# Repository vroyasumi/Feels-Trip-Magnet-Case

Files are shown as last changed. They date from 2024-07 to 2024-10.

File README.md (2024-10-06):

# Feels Trip Magnet Case (v1.1)

Intended for use with the Feels Trip PCB.¹

This case was designed with the intent of being manufactured via 3D Printers. Manufacturing via Resin and CNC has not been tested.

<sub>¹ Feels Trip PCB designed by CyberJedi.</sub>

## Updates (as of July 18, 2024)

v1 - Utilizes 12 magnets total.

v1.1 - Utilizes 20 magnets total; Updated magnet slots.

v1.2 TBA - Updated magnet slots to prevent magnet slippage; Added weight design

## Magnet Enclosure Preview (v1.1)

https://github.com/user-attachments/assets/327d06a7-1adf-4bc3-83b8-83f318915bca

## Supplies
[5x3mm Round Magnets](https://www.amazon.com/dp/B09QHS6VSJ)

[5x1mm Self-Adhesive Foam](https://www.amazon.com/dp/B07L6M4PN1)

Keyboard Feet of your choice.

Super glue of your choice.

Gloves to prevent sticking.

Paper towel to wipe excess glue.

## Build Instructions (Work In Progress)

Start on one case piece at a time.

1. Dab a drop of super glue on the magnet slot.
2. Place a magnet and hold the position for 1 minute. Wipe excess glue immediately after placing the magnet if necessary.
3. Before placing another magnet, test the polarity. All of the magnets must have the same polarity. If one magnet has the opposite polarity, the enclosure will become very weak regardless of how many magnets there are. Continue testing each magnet before gluing them in place.
4. Once all magnets are placed and have been checked for similar polarity, you may add more super glue to the exposed side of the magnets if necessary.
6. Before continuing on the other case piece, study the polarity on the initial case piece to make sure that you glue the next set of magnets correctly.
7. Continue Steps 2 through 4 for the other case piece. Again, you may add more super glue to the exposed side of the magnets if necessary.
8. Once finished, leave the super glue to cure. After 10 minutes of curing, test the polarity. Be careful though--the magnets are very strong and may shift or be ripped away from the slot. If this occurs, continue to cure for an hour before testing. After an hour, you may test the polarity of each magnet. If testing is successful, please cure for another 2 hours; or 24 hours to ensure secureness.

## Feels Trip Magnet Case (v1.1) Specifications

Design inspired by the Coriander, Wind x98, and Equinox.

### Front Height
20mm

### EKH
23mm

### Top Enclosure
L: 313.375mm

W: 118.588mm

H: 16mm

### Bottom Enclosure
L: 309.213mm

W: 114.705mm

H: 20.324mm

### Plate
L: 303.213mm

W: 110.425mm

H: 1.5mm - 1.6mm

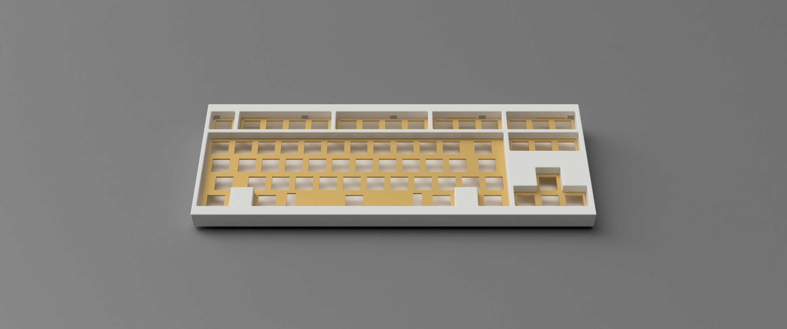
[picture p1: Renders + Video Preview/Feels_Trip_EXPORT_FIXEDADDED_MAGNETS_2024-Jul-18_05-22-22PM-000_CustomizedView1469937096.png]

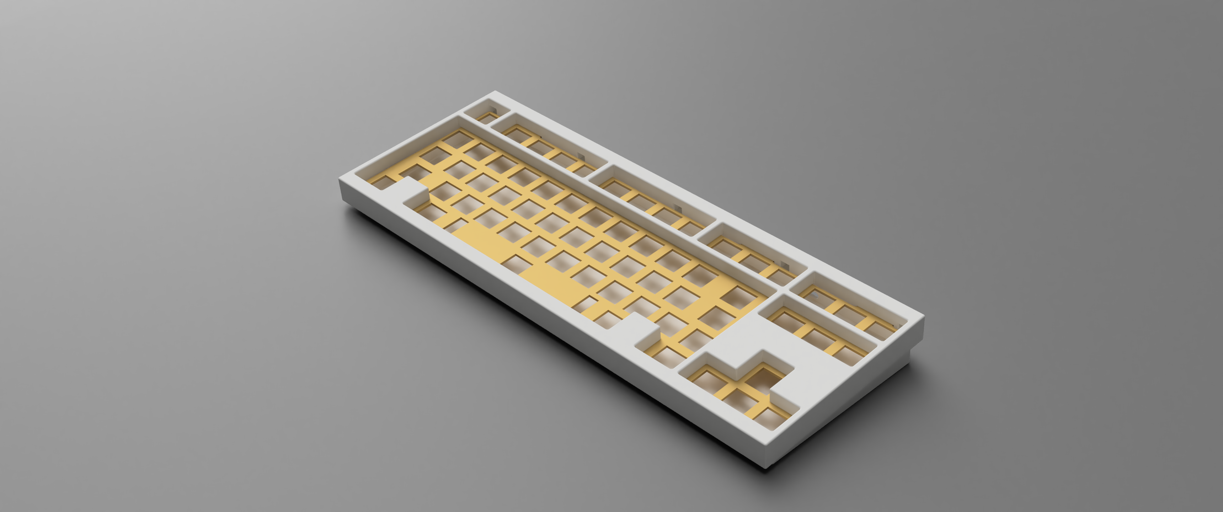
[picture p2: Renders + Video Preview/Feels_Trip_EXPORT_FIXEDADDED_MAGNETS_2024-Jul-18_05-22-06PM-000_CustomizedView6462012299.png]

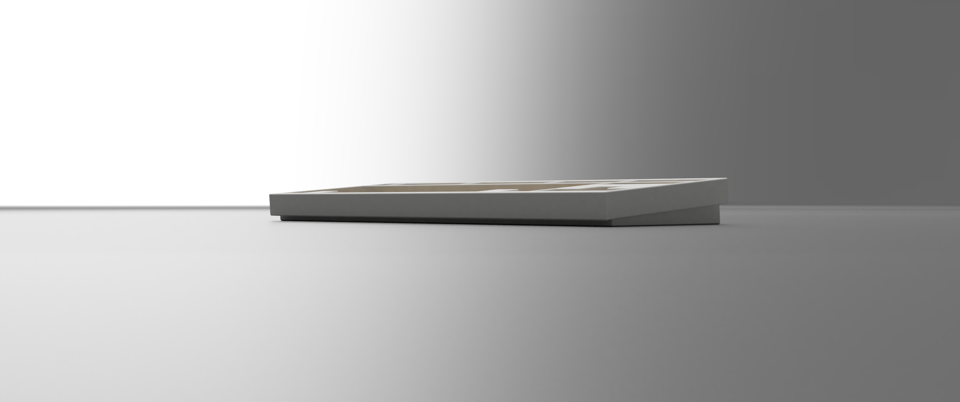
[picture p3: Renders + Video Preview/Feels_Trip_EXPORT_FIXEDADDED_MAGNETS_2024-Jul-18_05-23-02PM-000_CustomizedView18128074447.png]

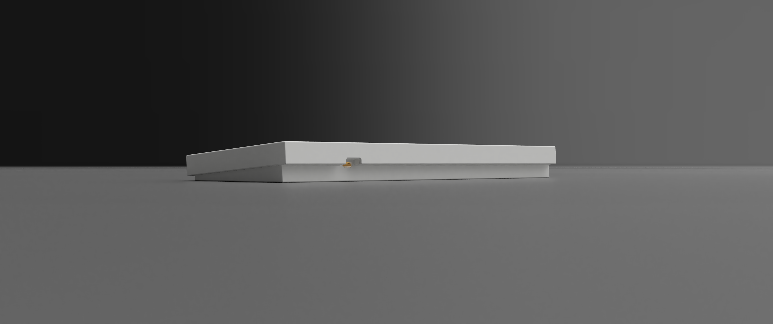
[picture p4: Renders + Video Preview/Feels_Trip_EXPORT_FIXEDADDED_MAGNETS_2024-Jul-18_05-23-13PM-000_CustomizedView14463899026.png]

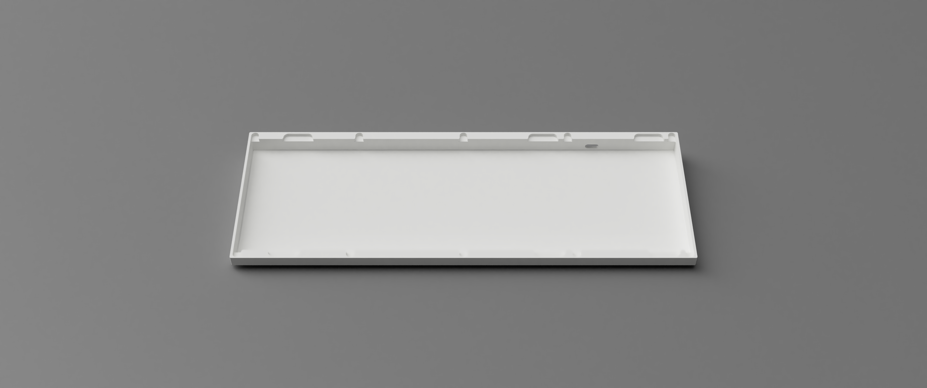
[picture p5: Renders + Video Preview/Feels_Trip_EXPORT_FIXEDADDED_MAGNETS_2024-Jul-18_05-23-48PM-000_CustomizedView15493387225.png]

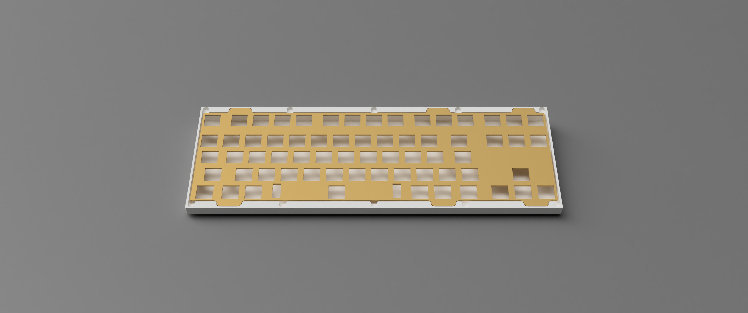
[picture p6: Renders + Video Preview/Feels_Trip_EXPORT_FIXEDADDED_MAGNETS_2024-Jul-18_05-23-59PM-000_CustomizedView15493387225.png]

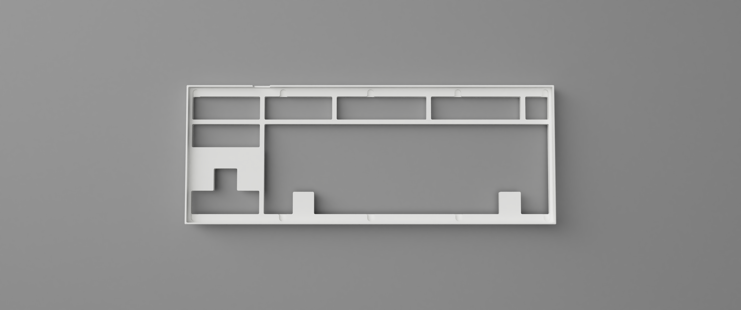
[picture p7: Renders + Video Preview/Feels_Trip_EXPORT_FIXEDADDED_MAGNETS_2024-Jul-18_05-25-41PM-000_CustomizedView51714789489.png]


## Notes

Special thanks to CyberJedi for helping me fulfill my 40% TKL passion.

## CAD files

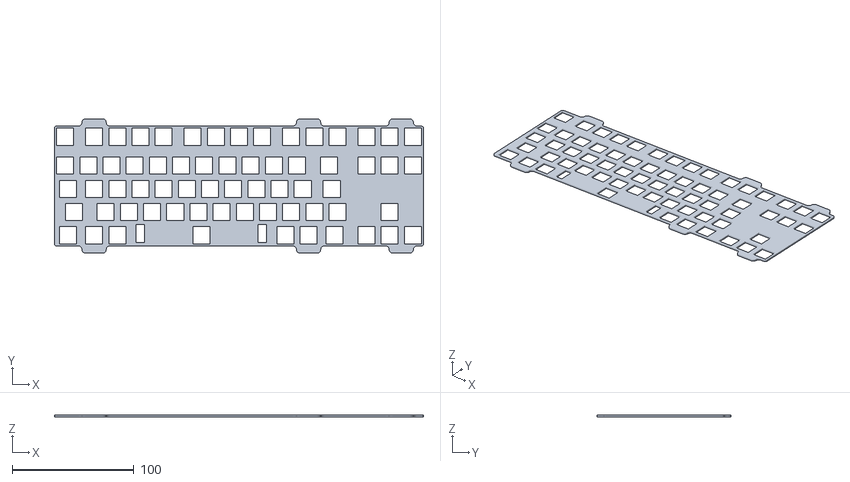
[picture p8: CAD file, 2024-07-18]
STL + DXF/Feels Trip Magnet Case Plate Final STL.stl
303.2 x 110.4 x 1.60

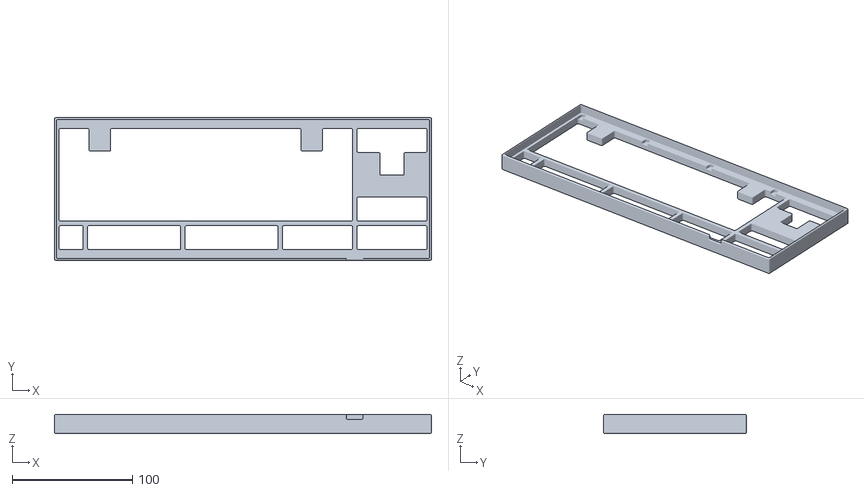
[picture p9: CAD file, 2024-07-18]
STL + DXF/Feels Trip Magnet Case Top Final STL.stl
313.4 x 118.6 x 16.0

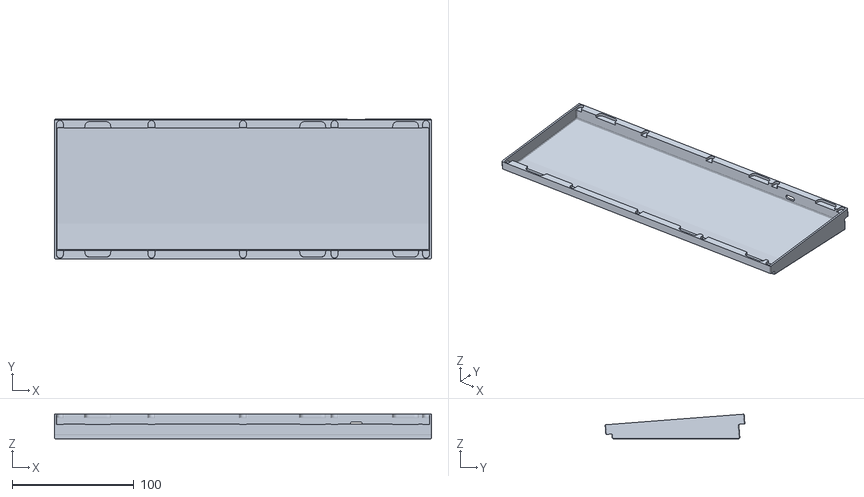
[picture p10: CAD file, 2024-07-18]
STL + DXF/Feels Trip Magnet Case Bottom Final STL.stl
309.2 x 114.7 x 20.3

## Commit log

2024-07-18 Added pictures of the Feels Trip Magnet Case
2024-07-18 Added STL files
    [Feels Trip Magnet Case Bottom Final STL.stl, Feels Trip Magnet Case Top Final STL.stl]
2024-07-18 Added Magnet Enclosure Preview
2024-07-18 renamed STL folder
    [Feels Trip Magnet Case Bottom Final STL.stl, Feels Trip Magnet Case Top Final STL.stl]
2024-07-18 Added Plate STL
    [Feels Trip Magnet Case Plate Final STL.stl]
2024-07-19 Added Plate DXF File
